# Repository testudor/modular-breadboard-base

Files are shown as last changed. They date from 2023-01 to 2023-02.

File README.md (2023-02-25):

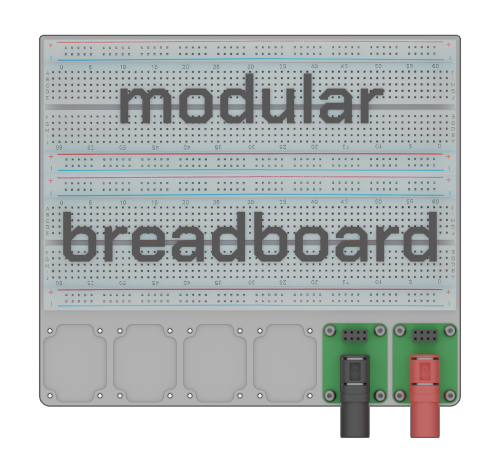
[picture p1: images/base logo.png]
modular breadboard


> **Warning** There will be an updated version of the breadboard base in the near future, which can either be machined from plastic or 3D printed. I plan to use threaded inserts, which will likely require slight adjustments to the mounting hole area. This would also mean that the keep-out zone for the PCBs will change slightly.

# Modular Breadboard

This is the main repository for the modular breadboard project and it also contains the 3D files for all available breadboard bases.

I decided to start this project because I wasn't happy with the quality of existing breadboard/banana-jack combinations and it kinda escalated from there.

# Modules

## Banana Bread

- Simple banana jack to female header adapter module
- Handles up to 24A in and 3A per pin out
- Supports both 'normal' banana jacks as well as the 'safety' type with an isolation sleeve
- For more info, click [here](https://github.com/testudor/banana-bread)

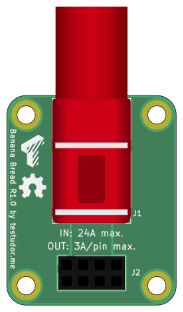
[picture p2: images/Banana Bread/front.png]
Banana jack module


## Serial Bread

- USB-to-UART converter
- Robust USB-C connector
- Switchable logic levels via jumper
- Provides up to 3A@5v and 600mA@3<area>.3V
- For more info, click [here](https://github.com/testudor/serial-bread)

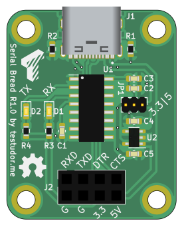
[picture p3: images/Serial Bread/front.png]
USB-to-UART module


## Template Bread

- KiCad template for creating new modules
- For more info, click [here](https://github.com/testudor/template-bread)

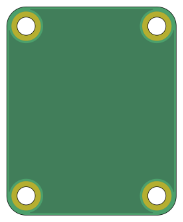
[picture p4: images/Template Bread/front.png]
template module


# Bases

## 1660-1

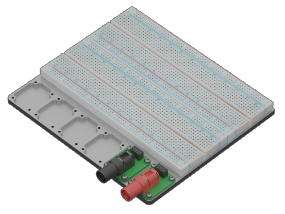
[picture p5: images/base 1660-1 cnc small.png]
1660 tie-point breadboard base


This base is meant for 1x1660/2x830 tie-point breadboards and the only one currently available

For more info, click [here](https://github.com/testudor/modular-breadboard-base/tree/main/base/1660-1).

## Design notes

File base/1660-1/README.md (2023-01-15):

# Base for 1x1660/2x830 Tie-Point Breadboards

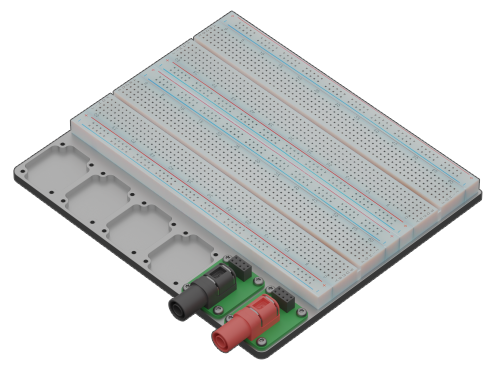
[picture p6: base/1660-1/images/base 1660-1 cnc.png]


This base is designed for one 1660 or two 830 tie point breadboards. High quality ones include the BusBoard BB830/BB1660 and the E-CALL EIC-102 (Also sold under a variety of other brands as EIC-102).

## CNC'd base

The file `base 1660-1 cnc.step` is meant for machines like a CNC router or CNC mill. It's 4.5mm thick and the prototype was machined from 5mm thick type 5083 aluminium with both sides faced. The mounting holes are 2.1 mm so they are ready for a standard M2.5 tap. 

Use M2.5x6 DIN 912 socket head cap screws to fix the PCBs to the base plate.

## 3D Printed base

The files `base 1660-1 3dp.step`/`base 1660-1 3dp.stl` are meant for 3D printers and offer another way to make a base for this project. As threads in plastic aren't too durable the screws are fastened to 24 M2.5 nuts embedded in the bottom of the base plate. 

Use M2.5x8 DIN 912 socket head cap screws to fix the PCBs to the base plate.

***As of now, this has not actually been printed yet***

## Additional Notes

Other types of M2.5 screws with the same length will also work. However it is important that the head size is <=4.5mm. Some module types have the upper copper pour connected to e.g. Ground. A too large screw head could potentially wear through the solder mask and connect the copper plane to the base plate which can lead to issues.

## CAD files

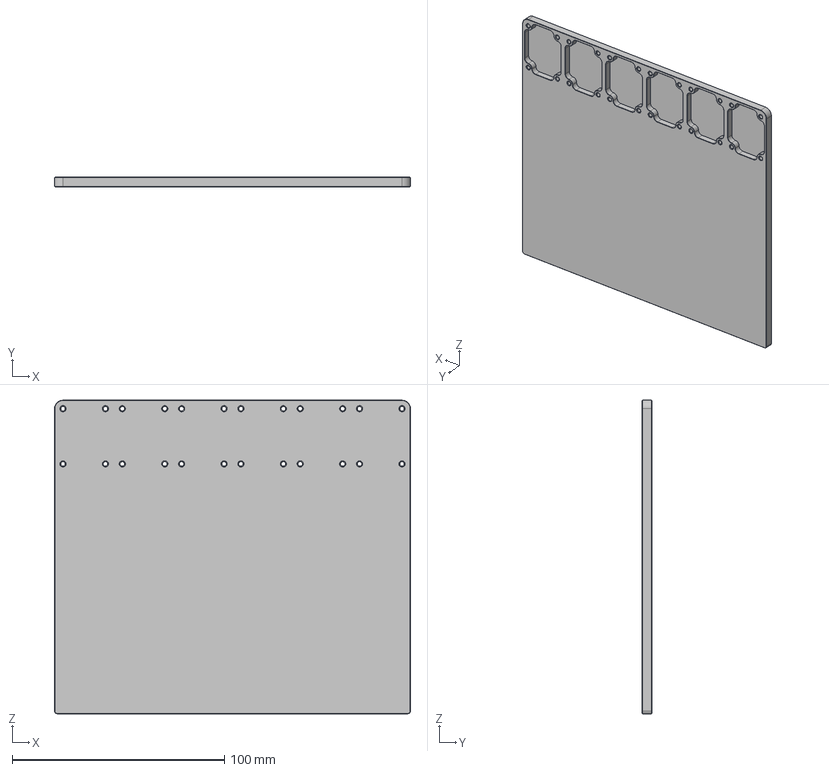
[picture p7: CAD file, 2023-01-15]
base/1660-1/base 1660-1 cnc.step
167.7 x 4.50 x 147.7 mm

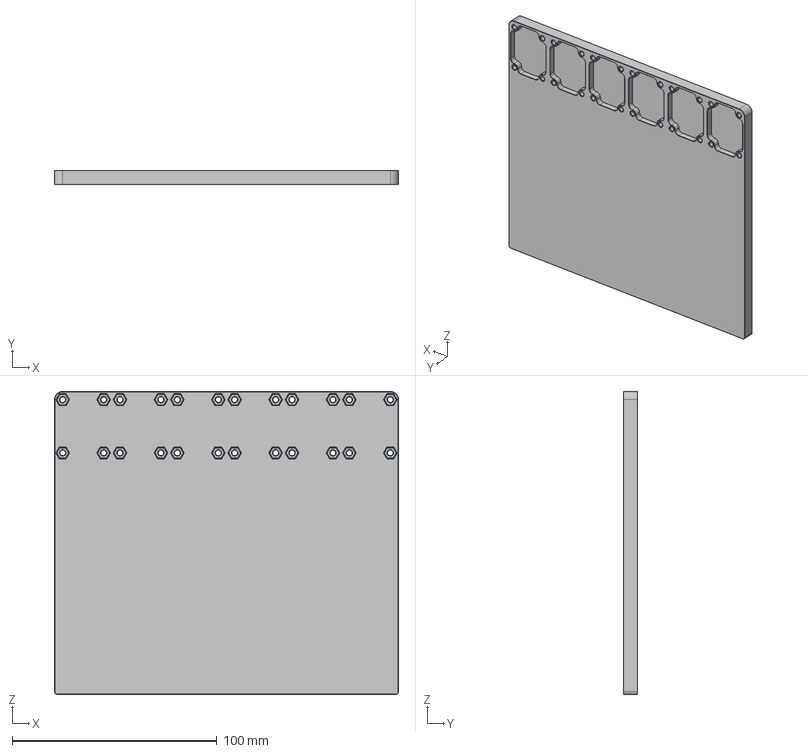
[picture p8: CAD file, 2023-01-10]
base/1660-1/base 1660-1 3dp.step
168.0 x 7.00 x 148.0 mm

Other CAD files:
base/1660-1/base 1660-1 3dp.stl

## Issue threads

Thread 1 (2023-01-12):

Module: USB-C PD to [5v/3.3v/etc?)

admalledd, 2023-01-12:
Using some trick such as [this](https://forum.digikey.com/t/simple-way-to-use-usb-type-c-to-get-5v-at-up-to-3a-15w/7016) to simply get 5V 3A from USB-C, and include a simple 5 volt to 3.3 volt regulator such that both voltages are available at the same time: have a single module that can provide the simple common power rails most breadboard projects desire.

Other inspiration products such as https://www.sparkfun.com/products/15801 require programming or a full microcontroller, and other easy purchases use mini or micro USB instead.

testudor, 2023-01-16:
I read up on USB-C PD myself and yeah, it's surprisingly complex. So I will probably work on a module which just uses the two resistors and a beefy regulator for 3.3 V first. In fact the serial module already has these resistors, just the regulator is pretty weak.

admalledd, 2023-01-16:
My biggest reason for a PD module was to have both the 3.3 and 5v at two or so amps, 10ish watts total. Many a time I have been testing things (with small servos before bigger just spinning free, LEDs, too many micros/chips...) and the more common 2.5w or 5w power supplies included with UART/Serial boards gets really annoying.

One option as a possibility is the 5v3a resistor layout, and then a "simple" [switching regulator like MP2152GTF-33](https://www.mouser.com/datasheet/2/277/MP2152-2945604.pdf) to also get a 3.3v rail derived from the 5v, not looking for higher voltages: I understand PD can get quite messy if you want anything more, not trying to ask for that, and if someone does there are "better" off-breadboard adjustable supplies to turn to.

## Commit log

2023-01-10 Add readme for 1660-1 base
    [base 1660-1 3dp.step, base 1660-1 3dp.stl, base 1660-1 preview.stl]
2023-01-11 Add note for 3D printed base
2023-01-15 changed module distance to be a multiple of 2.54
    [base 1660-1 cnc.step]
2023-01-15 fix wrong plate thickness
    [base 1660-1 cnc.step]
